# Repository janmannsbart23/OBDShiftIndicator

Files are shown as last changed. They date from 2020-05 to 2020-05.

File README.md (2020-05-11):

# OBDShiftIndicator
OBDShiftindicator is 

  - An indicator for gearshift in your car (widely know in race cars)
  - Working in every car that has an OBD2 port
  - Open Source
  - Developed as a hobby project 

Video:

(https://www.youtube.com/watch?v=m7eosfVUVjs)

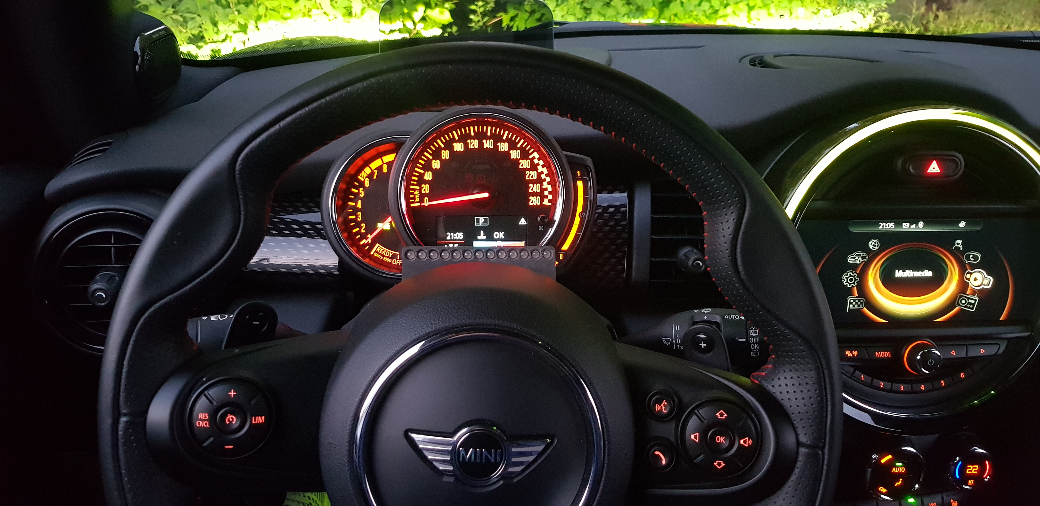
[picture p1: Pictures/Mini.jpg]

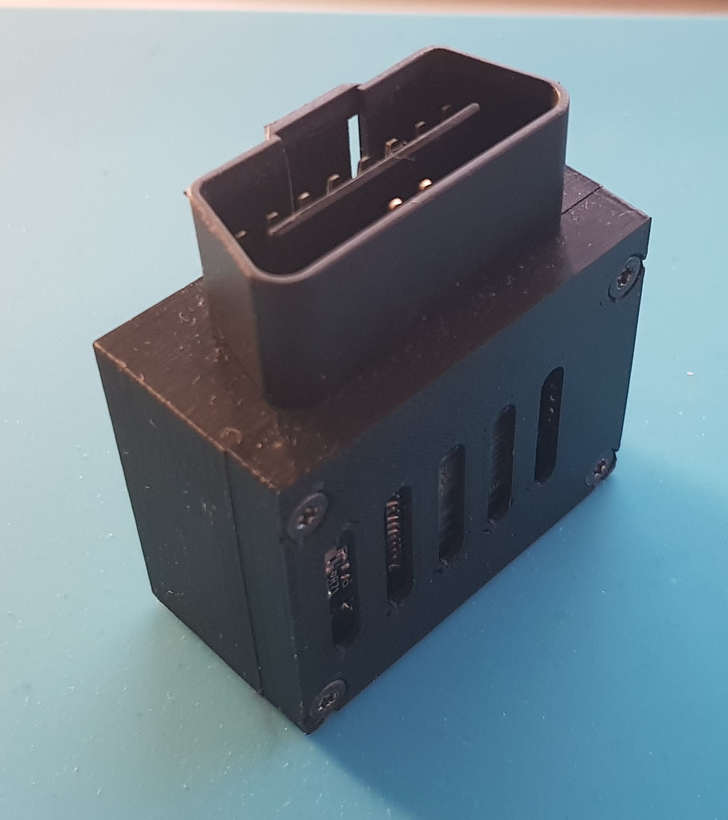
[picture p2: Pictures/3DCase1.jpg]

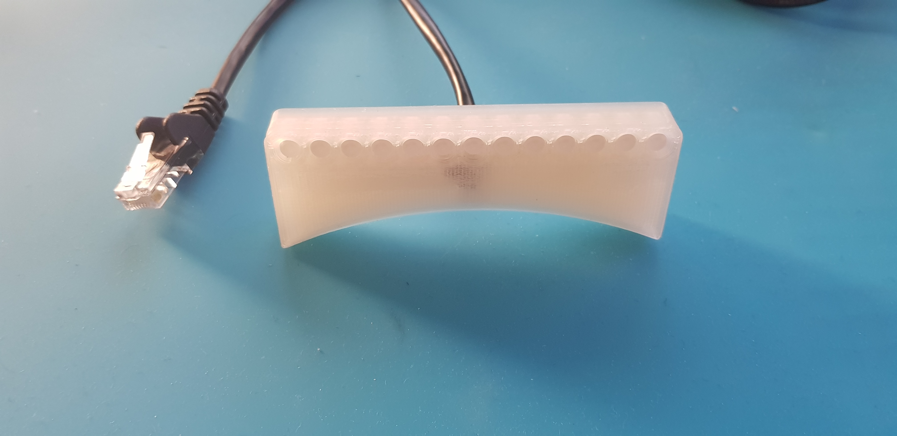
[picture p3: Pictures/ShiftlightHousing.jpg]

# Complete Project!

  - The Project contains anything you need to build a working shiftindicator on your own including a pcb, a housing and code for running it.
  - It was developed over a long period as a hobby and is constantly improving
  - Just plug it into your cars' OBD2 port and connect the shiftlights via the RJ45 connector.

# Four Main Components

The ShiftIndicator consists of three main components

* PCB for mainboard and shitindicator-board
* 3D printed housing (designed for a mini cooper (easy to be adapted))
* Code for microcontroller
* Code for an android app to controll it and see telematic data

# Features
The Hardware and Software featues:
* quiescent current safety. when the obd gateway shuts down, the can tranciever shuts off the 12Vto5V voltage regulator
* low standby current consumption -> it consumes arround 60uA while standby
* when the car can wakes up, it automatically wakes up the hardware
* fused input
* OTA update capability
* Bluetooth connection to your android phone to control brightness, switch on and off and see some telematic data

# 3D Housing

The 3D housing was designed in solid edge. Besides the solid edge files the .stl files are provided. They can straight up be printed. 
The files can also be imported in fusion360 and modified.

# Hardware
The hardware was created with EasyEDA. Gerbers and a BOM are provided. The shiftlight is connected via RJ45 to the mainboard. On one end, the cable has to be cut and soldered to the shiftligh-pcb.

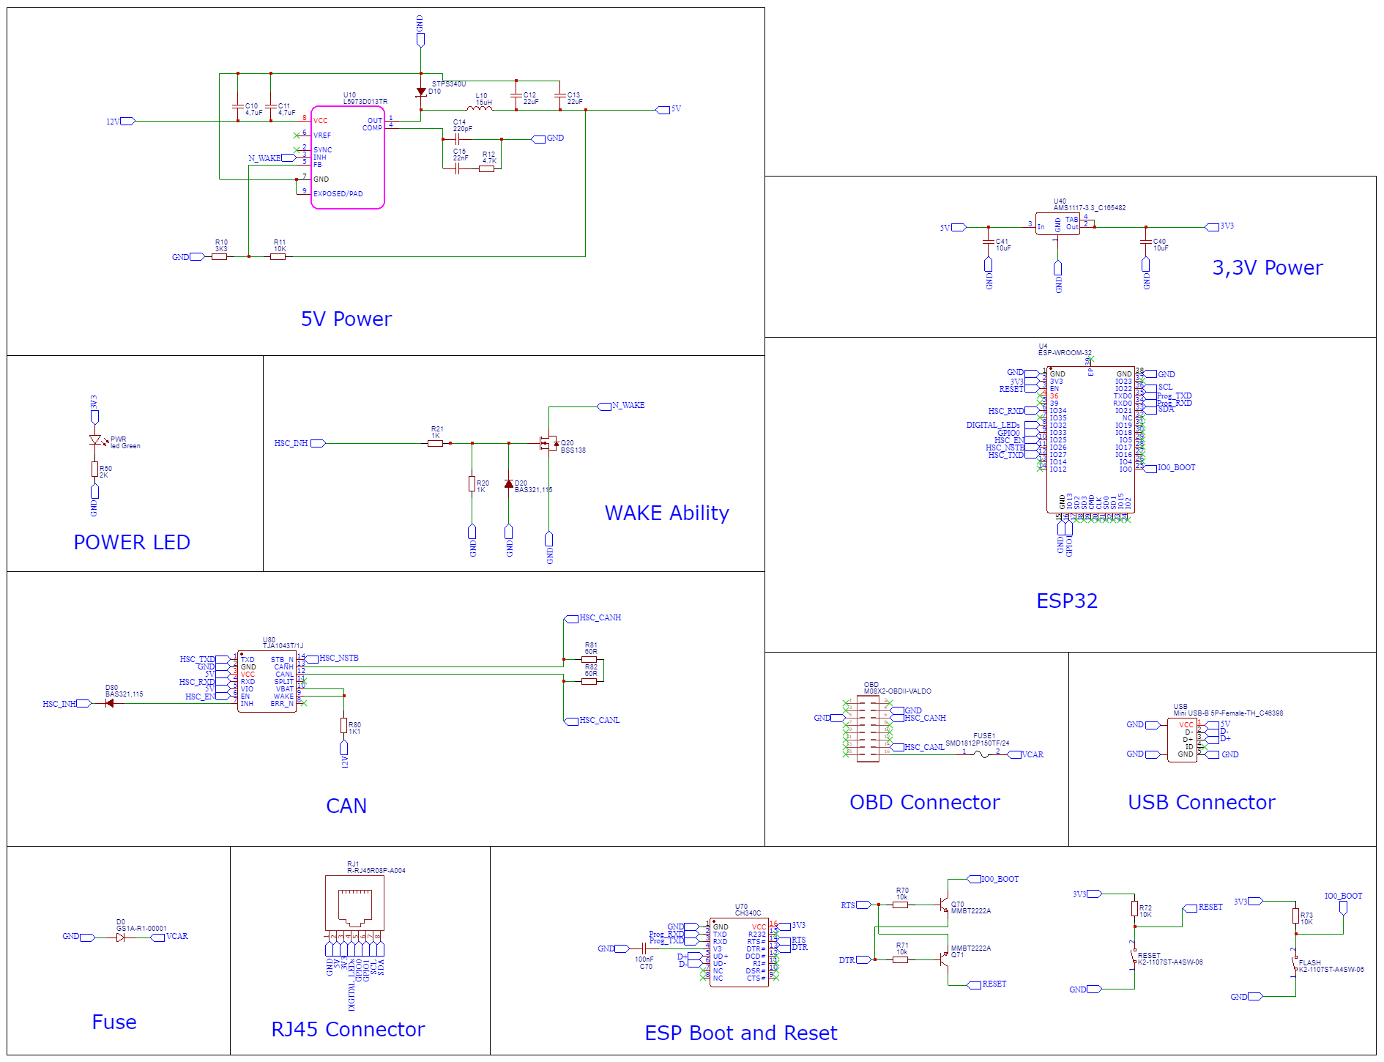
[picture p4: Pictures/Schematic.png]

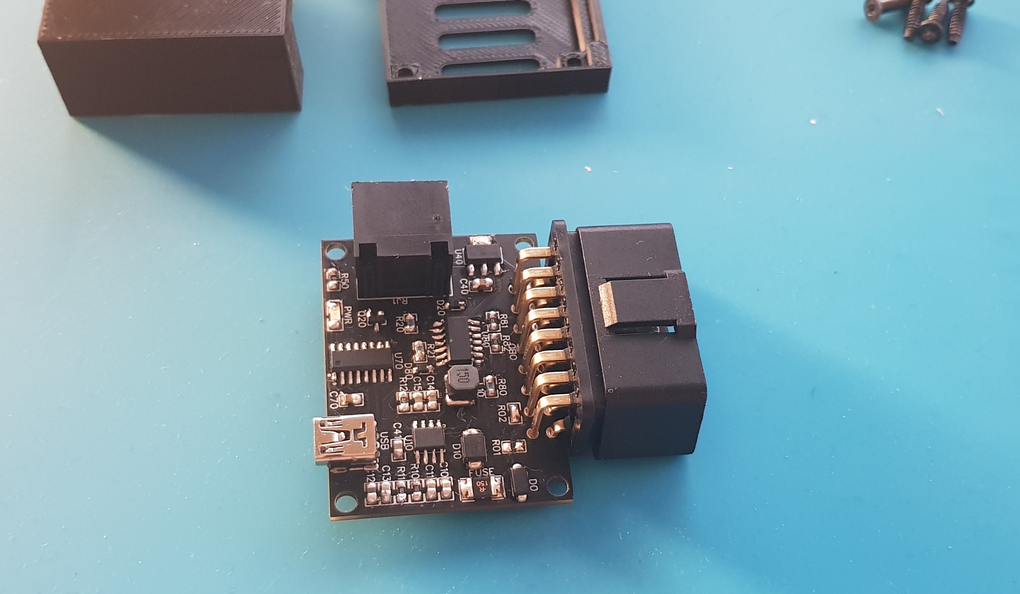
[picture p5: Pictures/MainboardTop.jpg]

# Code

The code was developed using the arduino core for the esp32. For multithreading FreeRTOS was used. 
The provided platformIO projekt will manage all required libraries.

# Contribution
I would be very happy if there are some interested people who like this project and maybe even try it yourself. Since the system itself was developed for a mini cooper, there are certainly things that should be adapted if it should be used in other vehicles (rpm, 3d housing, etc.). For questions, I am always available.

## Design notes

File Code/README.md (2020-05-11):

# Mainboard Code
- Import the project in PlatformIO
- If you want to have OTA update functionality, go to "CWifiCredentials.hpp" and enter the Wifi credentials for the wifi it should connects to. Currently only client mode is implemented. After that, open "DConfig.hpp" and set "IS_OTA_FUNCTIONALITY_ENABLED" to true
- Upload the Project to the ESP32 via the onboard USB2Serial Chip. (Very lickely that you have to adjust the COM-Port in the platformio.ini)
- The code also saves the brightness values and if the shifter is activated in eeprom. This can be changed via the android app. After the first time uploading, there will me most likely 0xFF in the eeprom, which means the shifter is deactivated and will never light up. This can be changed via the app. If you dont want to use the app, you can override the values via the "DConfig.hpp" file. Set "FIRST_LAUNCH_SETTINGS_OVERRIDE" to true and upload the code. Connect with a terminal to the COM-Port and check the response. If it was successful, change the value back to "false". Now it will work as intended.

- The Code waits until a rpm of at least 500 is detected to ensure that the motor was started. After that, a animation with blue lights will show up on your shiftlights. After that, it waits until an engine oil temperature of 90 degree is reached (to be sure ur engine is hot enough :) ). A green led animation will show up. After that the shiftlight-mode is active and will light up depending on your rpms. Those values can be changed in "CShiftLedTask.cpp"

# Android APP Code
- The Android App is under heavy construction at the moment. It's an proof of concept and working fine at the moment. The design is just not great... If you can design nice apps, please contact me :D

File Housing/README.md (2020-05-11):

# Housings
Initialy the housings were designed in Solid Edge. The Solid Edge .par files can simply be imported into fusion360 and edited to your needs.

The housing for the shiftlights is designed for an MINI F56 but can also be simply be adapted.

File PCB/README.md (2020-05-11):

# OBDShiftIndicator PCBs
There are two PCBs:

  - OBDMainboard: The Mainboard containing the ESP32, OBD-Connector, Powermanagement and CAN-Tranciever



  - Shiftlight: Contains the LEDs for the Shiftlight



# OBDMainboard

  - BOM is included. I got the OBD-Connector from Aliexpress due to a lack of availability. The project can also be found on EasyEDA

  https://easyeda.com/mannsbart.jan/obdshiftindicator-mainboard

# Shiftlights

  - BOM is included. The project can also be found on EasyEDA 
  - A photoresistor and a button can also be placed on the pcb. Currently these features are not supported in the firmware, but can easily be implemented
  - Important: To easily connect the Shiftlight-PCB to the Mainboard-PCB you have to cut an RJ45 Cable in half and solder 3 wires to the Shiftlight-PCB (VCC/GND/WS2812). Please check the RJ45 Pinout of the Mainboard-PCB and the corresponding wire colors

https://easyeda.com/mannsbart.jan/obdshiftindicator-shiftlights

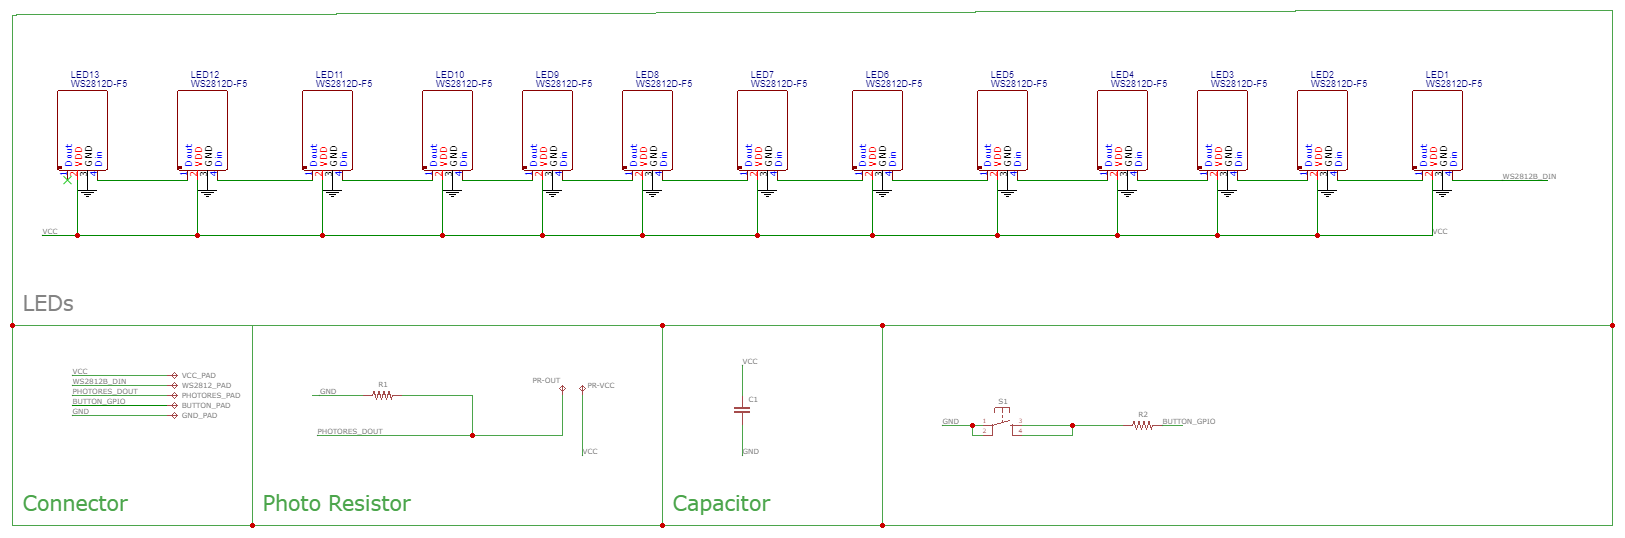
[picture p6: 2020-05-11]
Pictures/ShiftlightsSchematic.png

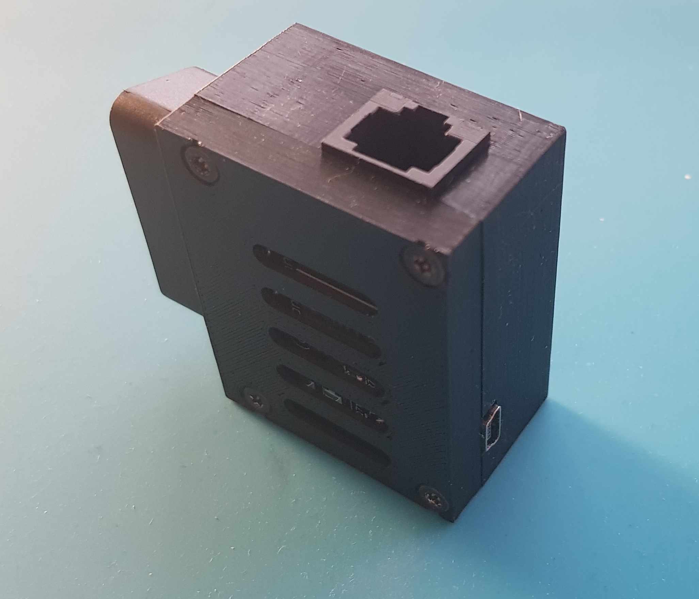
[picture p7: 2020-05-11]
Pictures/3DCase2.jpg

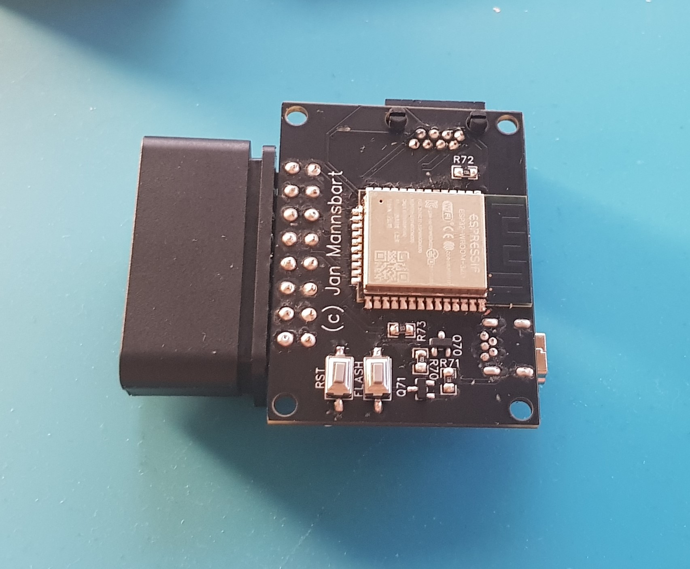
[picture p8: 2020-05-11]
Pictures/MainboardBot.jpg

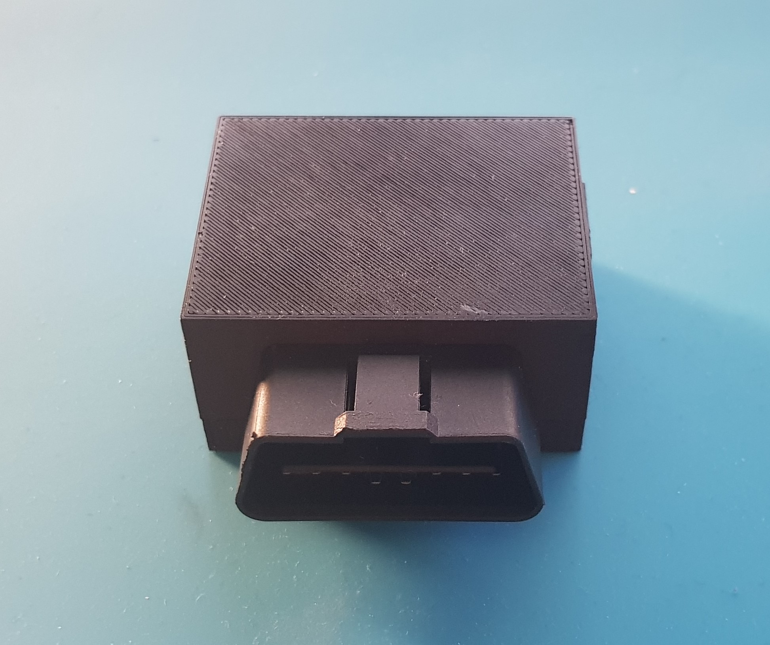
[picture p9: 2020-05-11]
Pictures/3DCase3.jpg

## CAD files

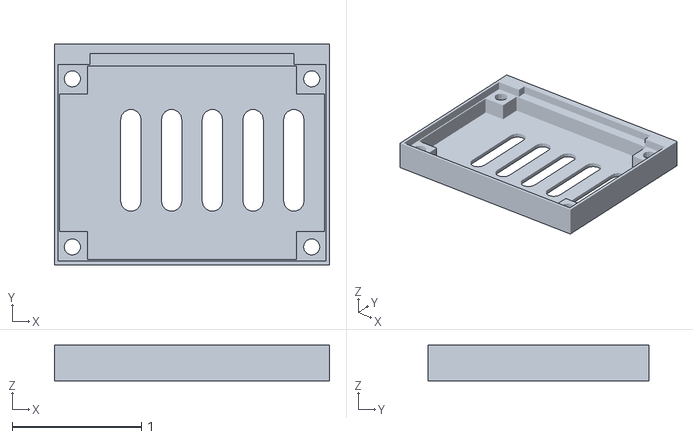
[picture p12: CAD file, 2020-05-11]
Housing/OBDMainboardHousing/OBD_Case_Bottom.stl
2.13 x 1.70 x 0.276

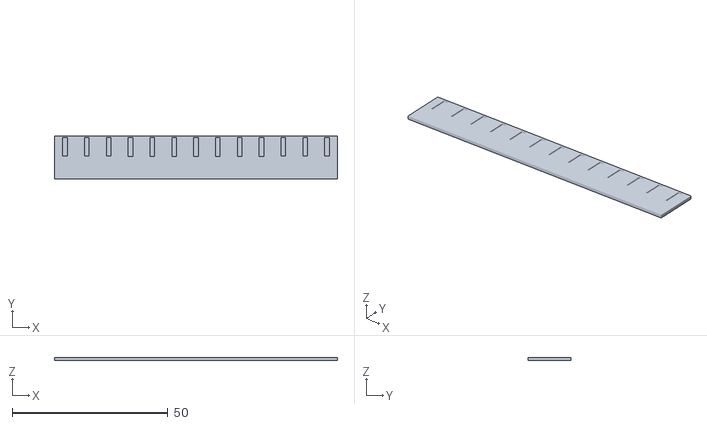
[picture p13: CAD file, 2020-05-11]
Housing/ShiftLightHousing/Backcover.stl
90.8 x 13.6 x 1.00

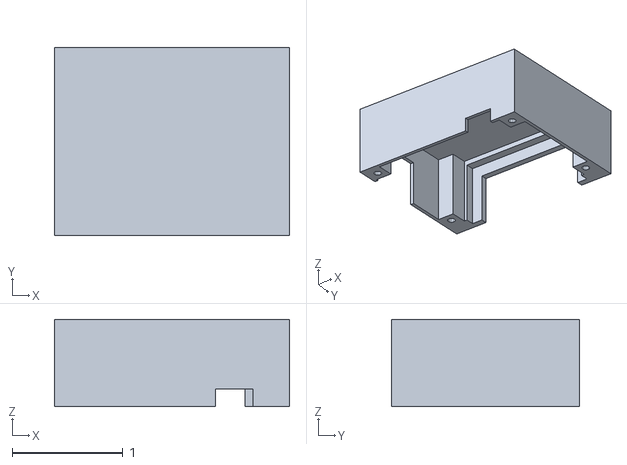
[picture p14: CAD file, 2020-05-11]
Housing/OBDMainboardHousing/OBD_Case_Top.stl
2.13 x 1.70 x 0.787

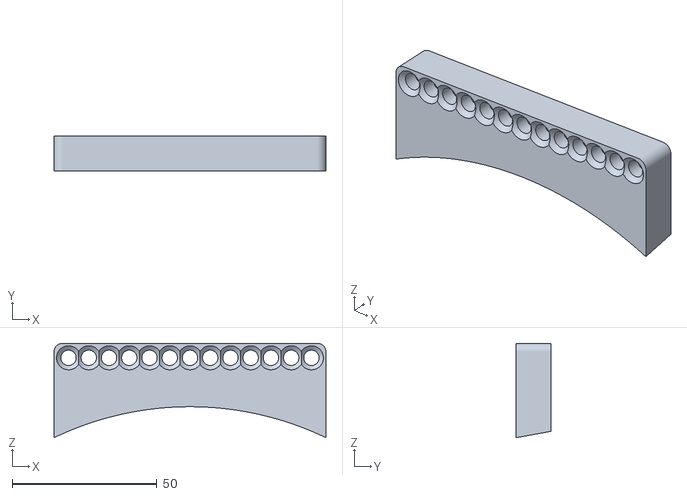
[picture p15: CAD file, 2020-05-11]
Housing/ShiftLightHousing/Shiftlights.stl
94.1 x 12.1 x 32.7

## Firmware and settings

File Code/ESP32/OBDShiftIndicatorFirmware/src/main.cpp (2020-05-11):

#include <Arduino.h>
#include "CCarInfoSystem.hpp"
#include "DConfig.hpp"
#include <EEPROM.h>

void setup()
{
  Serial.begin(115200);

  if (FIRST_LAUNCH_SETTINGS_OVERRIDE)
  {
    EEPROM.begin(EEPROM_STORAGE_SIZE);
    EEPROM.write(EEPROM_SHIFTLIGHT_ACTIVE_BYTE, 1);
    EEPROM.write(EEPROM_SHIFTLIGHT_BRIGHTNESS_BYTE, 128);
    EEPROM.commit();

    while (true)
    {
      Serial.println("EEPROM values overwritten! Change 'FIRST_LAUNCH_SETTINGS_OVERRIDE' to false again!");
      delay(1000);
    }
  }

  CCarInfoSystem *carInfoSystem = new CCarInfoSystem();
  carInfoSystem->StartSystem();
}

void loop()
{
  delay(1000);
}

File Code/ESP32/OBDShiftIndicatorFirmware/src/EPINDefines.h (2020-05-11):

#ifndef PINDEFINES_H
#define PINDEFINES_H

namespace ePIN
{
typedef enum
{
  CAN_RX = 34,
  CAN_TX = 27,
  CAN_EN = 25,
  CAN_NSTB = 26,
  I2C_SDA = 21,
  I2C_SCL = 22,
  DIGITAL_LEDS = 32,
  GPIO2 = 13,
  GPIO1 = 14,
  GPIO0 = 33,
  VSPI_CS = 5,
  VSPI_CLK = 18,
  VSPI_MISO = 19,
  VSPI_MOSI = 23,
  STATUS_LED = 17
} ePIN;
}

#endif
